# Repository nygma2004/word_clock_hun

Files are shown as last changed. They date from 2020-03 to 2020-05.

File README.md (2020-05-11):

# Word Clock Hungarian
This is my implementation of the Word Clock in Hungarian. Rest of the document is in Hungarian, English of this [document is here](README_EN.md).

## Változások
1.0
- Egyes mudulok külön header fájlokba lettek szétszedve

0.9
- Kód első verziója, az alap funckiók működnek
- Fényerő szabályzás még nem működik

## Főbb funkciók
- 10x10 mátrixban elhelyezett magyar szavakkal mutatja az aktuális időt 5 perces pontossággal
- Az egyes szavak színe a napszaknak megfelelően, nappal fehér, este kékes, naplementekor piros, napfelkeltekor narancssárgás és között 1 órát átmenet
- A pontos időt NTP szerverről szedi, kézi beállítás nincs
- Minden egész perckor rövid animálás van, amikor 8-10 véletlenszerű betű felvillan véletlenszerű színnel
- MQTT szerverre minden percben küld egy státus üzenetet: RSSI, uptime percben és a érzékelt fényerő
- MQTTn keresztül figyel egy sleep topic-ra, ahova ha 1-es érkezik akkor lekapcsolja a kijelzőt

A projekt teljes bemutatása ezen a videón megnézhető: 
https://youtu.be/ypevX-sNXiU

## Telepítés
- A kód Arudino IDE alatt kell elfordítani, ami ESP8266 alá be van konfigurálva
- Szükséges libraryk: PxMatrix LED MATRIX library by Dominic Buchstaller, Time by Michael Margolis (ezek megtalálhatók a Library Manager-ben), és persze az ESP alap libraryk, PubSubClient, stb.
### Projekt fájljai:
- WordClock_PxMatrix.ino: teljes programkód, ebben nem kell semmit módosítani ha ugyan ezt a kijelzőt használod és szintén magyar a kijelző
- settings.h: ebbe található a program beállításához szükséges össze paraméter
  - ANALOG_LOW: a legkisebb mért fény mennyiség (A0 analóg jel értéke)
  - BRIGHTNESS_LOW: a fenti érték esetén a kijező minimális fényereje
  - ANALOG_HIGH 120: a legnagyobb mért fény mennyiség (A0 analóg jel értéke)
  - BRIGHTNESS_HIGH: a fenti érték esetén a kijező maximális fényereje
  - ssid: wifi SSID
  - password: wifi jelszó
  - mqtt_server: MQTT szerver IPje, vagy maradjon üres ha nem kell
  - mqtt_user: MQTT usernév
  - mqtt_password: MQTT jelszó
  - clientID: MQTT klines ID
  - topicstatus: az MQTT topic amire az óra küldi percenként a státusz üzenetet
  - topicDebug: az MQTT topic amire a debug üzenetek mennek
  - topicSleep: az MQTT topic amire várja a sleep üzentetet
  - STATUS_UPDATE_INTERVAL: státusz MQTT üzenet gyakoriság másodpercben
  - ANIMATION_WORD_COUNT: minden percben a rövid animációban kigyújtütt betűk száma
  - ANIMATION_WORD_DELAY: az animációban az egyes betűk közötti késletetés miliszekundumban
- NTP.h fájl 63 sorától pár beállítás
  - GMTOffset: időzóna percben CET esetén ez 60
  - sm_latitude, sm_longtitude: földrajzi szélesség és hosszúság a napfelkelte, napnyugta számításhoz
- Arduino Board Configuration amit én használtam: LOLIN(WEMOS) D1 R2 mini, 4MB Flash size

## PCB
Minden részletesebb leírás nélkül egyelőre itt az általam használt PCB: https://www.pcbway.com/project/shareproject/PxMatrix_ESP8266_Driver.html
img könyvtárban van egy kép hogy néz ki. Ennek a leírása kicsit hosszú inkább mesélek róla a Youtube videóban.

## Hardver
- 32x32 pixeles, 192x192 mm P6 matrix kijelző: https://www.aliexpress.com/item/32658820147.html
- Wemos D1 mini klón: ebay, aliexpress, banggood, én már nem emlékszem az enyém honnan van
- 0.1 inch-es tűsor és csatlakozó 
- jumperek
- 0.2 inch-es csavaros 2 pólusú csatlakozó
- fotóellenállás

A PI és PO csatlakozóhoz nem vettem szabványos dugót és ajzatot, hanem sima egy soros tűsort és csatlakozót használtam, kéttőt egymás mellett és tökéletesen működik. Sőt a PO és a tápcsatlakozó olyan közel van egymáshoz hogy ott nem és férne el rendes ajzat. Viszont cserébe figyelni kell hogy dugja be az ember a dolgokat. Ahogy a képen is látszik a kijelzőn nyák lapján lévő nyilacskák balról jobbra mutassanak, és a PO csatlakozóba a szalagkábelt úgy kell bedugni hogy a csatlakozó oldalán a kiugrás a ESP felé legyen.

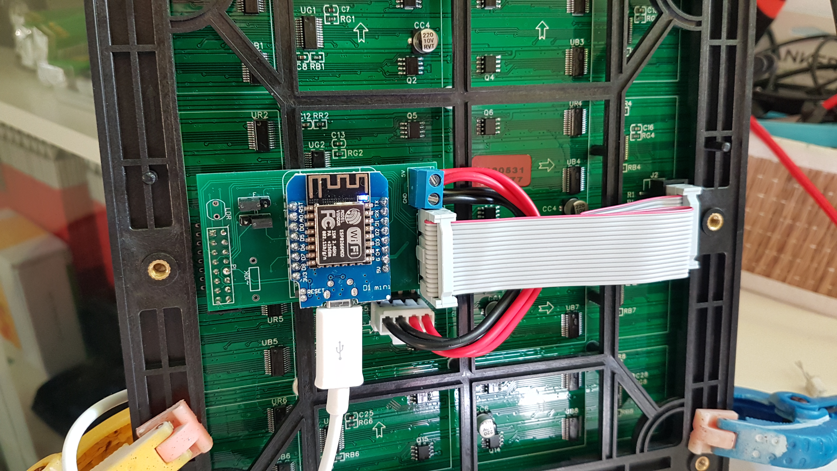
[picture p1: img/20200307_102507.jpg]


A nyákon a táp csatlakozó 5V és GND vezetéke össze van kötve a ESP 5V és GND lábával, így lehet a kijelzőt az ESPn keresztül microUSB csatlakozón keresztül hajtani, vagy más tápellátás esetén azt is a tápcsatlakozóra kötni és akkor azt ad áramot az ESPnek. Az én programom esetén ahol egyszerre sosem világít túl sok LED, USB tápról lehet a kijelzőt hajtani.
A P6-os matrix kijelző esetén a jumpereket a fenti képen látható módon kell elhelyezni.
Ez a Word Clock mivel egy időben az összes LEDnek csak viszonylag csak a kis része világít, átlagosan 250-300 mA-t fogyaszt. Így szerintem egy rendes 1A-es USB töltőről működtethető, nincs szükség külön 5V-os tápegységre.

## Fényerő szabályzás

A nyákon van hely egy fotoellenállás számára. Én itt nem vágtam le a fotoellenállás lábát, tettem rá zsugorcsövet és kihajlítottam hogy oldalt méreje a fényerőt. Ha jól emlékszem olyan LDR-t vettem ami 5K max megvilágítás mellett. Ehhez egy 5K-s ellenállást forrasztottam az ellenállás helyére (ahol a nyákon 10K felirat szerepel):

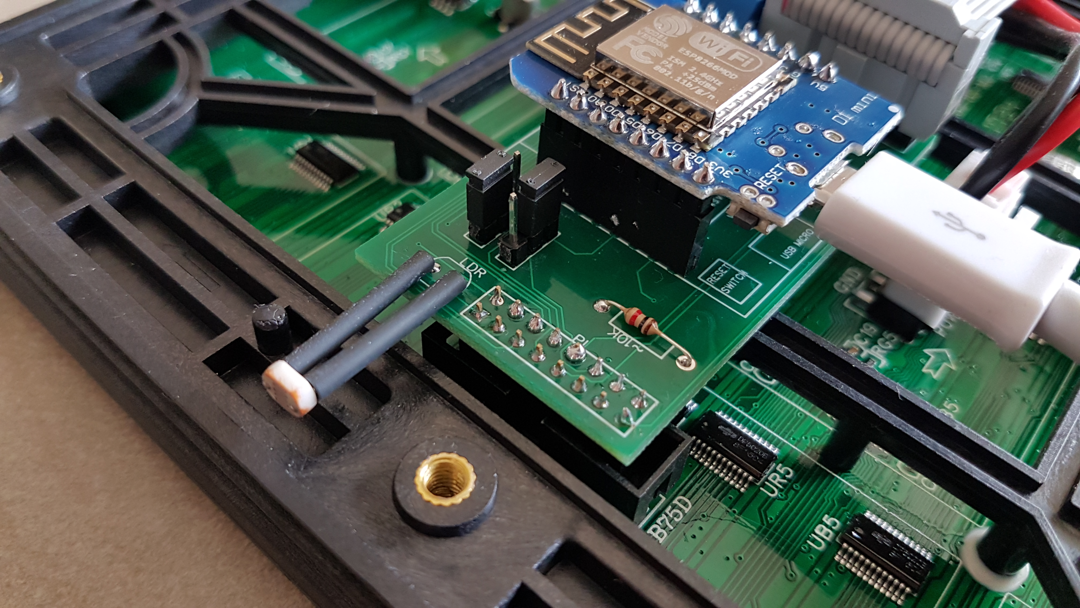
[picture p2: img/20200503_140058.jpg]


Így a max fényerő amit a ESP mér az olyan 400 körül van, de ahhoz hogy megállapítsam a háttérfényerősséget bőven elég. A beállításokban van 4 érték ami meghatározza hogy minimális analóg jel esetén mi legyen a kijelző fényereje és ugyan ez maximum esetén. Ezzel lehet játszani. Kettő között pedig arányosan alakul a fényerő mértéke.

## 3D nyomtatott alkatrészek és előlap
Az összes forrás és gcode fájl a 3D könyvtárban található. Teljes modell az alábbi részekből áll:
- 10x10 raster: ez a kijelzőt lefedő rács ami a 3x3 pixeles szavak megvilágító dobozokat előálltja
- 4 corners: ez jön a kijelző 4 sarkára. Ezt külön nyomtattam mert egyben nem fért volna bele a 3D nyomtató korlátaiba. Mind a 4 elem kicsit más, mindegyik a megfelelő sarokba kerüljön különben nem tökéletesen illeszkedik
- Lower corners: ez fogja meg a rácsot a másik oldalról, illetve eltartja a kijelzőt mondjuk a faltól hogy az elektronika elférjen
- Hanger support: egy kis kúp alakú elem amivel fel lehet akasztani egy szögre
- Cable holder: szintén egy kúpos elem amivel a kábelt lehet a falnál tartani, illetve hogy ne az USB csatlakozót húzza a kábel súlya

Itt látható az előlap a raszterrel és a 4 sarok elemmel amik pillanat ragasztóval vannak összeragasztva:
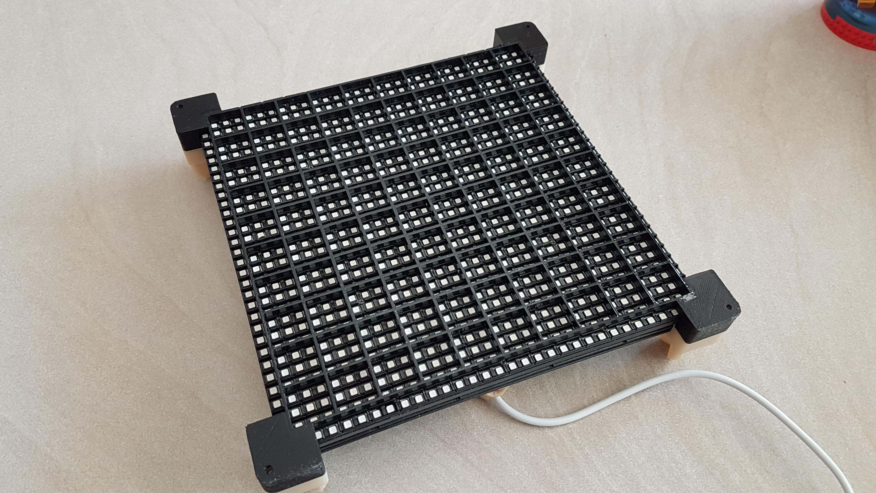
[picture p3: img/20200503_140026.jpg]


Kicsit közelebbről a sarok és hogyan illeszkedik a kijelző mélyedéseibe:
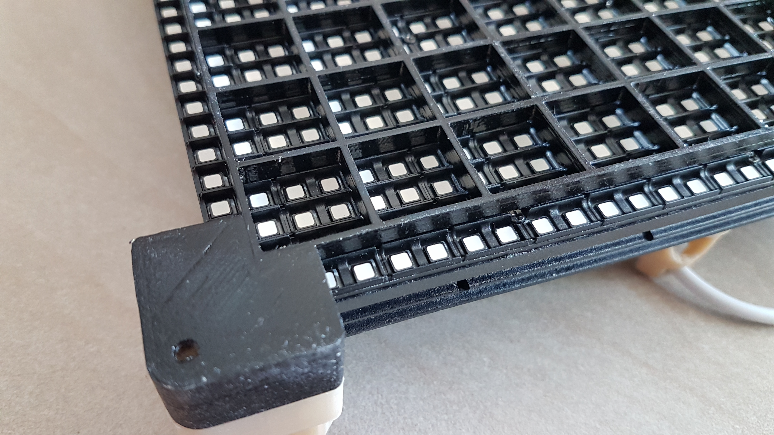
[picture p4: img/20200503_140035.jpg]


És a hátlap elemei:
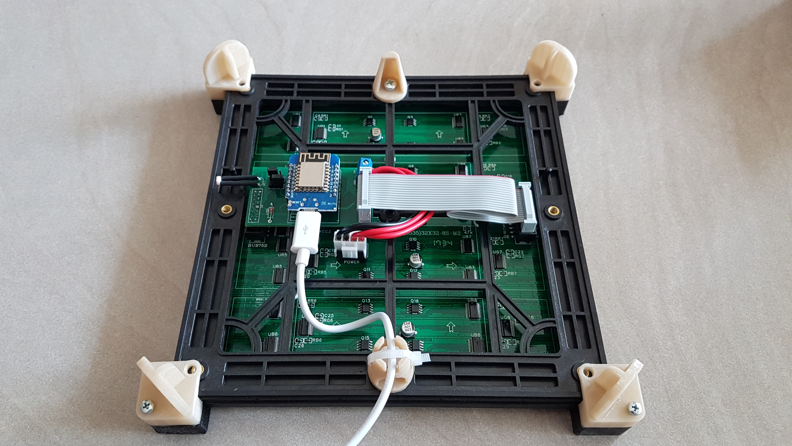
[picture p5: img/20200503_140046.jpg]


Az én órám esetén a számlap 1.5 mm vastag szénacél lemez, amiből a betűk lézervágással lettek kivágva. A lemezt 150-es csiszolópapírral kézzel csiszoltam és utána lakkal befújtam hogy ne rozsdásodjon. A lemez és a raszter háló közé pedig pausz papír került hogy ne látszanak a LED-ek. A design alkönyvtárban van egy dxf, dwg meg pdf terv is. Ezeket a fájlokat küldtem egy egy CNC cégnek és ez alapján vágták ki nekem az előlapot.

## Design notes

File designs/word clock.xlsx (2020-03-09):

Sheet: Sheet1
 |  | 0 | 1 | 2 | 3 | 4 | 5 | 6 | 7 | 8 | 9
0 |  | Ö | T | B | T | Í | Z | J | A | S | U
1 |  | P | E | R | C | C | E | L | E | W | O
2 |  | M | Ú | L | T | A | M | Ú | L | V | A
3 |  | H | Á | R | O | M | U | F | É | L | J
4 |  | N | E | G | Y | E | D | X | H | A | T
5 |  | N | É | G | Y | A | H | Á | R | O | M
6 |  | N | Y | O | L | C | Ö | T | H | É | T
7 |  | T | I | Z | E | N | E | G | Y | E | B
8 |  | T | I | Z | E | N | K | E | T | T | Ő
9 |  | K | I | L | E | N | C | Q | Ó | R | A
 | Calculator
 |  | 0 | 1 | 2 | 3 | 4 | 5 | 6 | 7 | 8 | 9
0 |  | Ö | T | B | T | Í | Z | J | A | S | U | 0x
1 |  | P | E | R | C | C | E | L | E | W | O | 1x
2 |  | M | Ú | L | T | A | M | Ú | L | V | A | 2x
3 |  | H | Á | R | O | M | U | F | É | L | J | 3x
4 |  | N | E | G | Y | E | D | X | H | A | T | 4x
5 |  | N | É | G | Y | A | H | Á | R | O | M | 5x
6 |  | N | Y | O | L | C | Ö | T | H | É | T | 6x
7 |  | T | I | Z | E | N | E | G | Y | E | B | 7x
8 |  | T | I | Z | E | N | K | E | T | T | Ő | 8x
9 |  | K | I | L | E | N | C | Q | Ó | R | A | 9x
 |  | 0 | 1 | 2 | 3 | 4 | 5 | 6 | 7 | 8 | 9

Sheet: Sheet2
3:00:00 | Ö | T | B | T | Í | Z | J | A | S | U | 0x
 | P | E | R | C | C | E | L | E | W | O | 1x
 | M | Ú | L | T | A | M | Ú | L | V | A | 2x
 | H | Á | R | O | M | U | F | É | L | J | 3x
 | N | E | G | Y | E | D | X | H | A | T | 4x
 | N | É | G | Y | A | H | Á | R | O | M | 5x
 | N | Y | O | L | C | Ö | T | H | É | T | 6x
 | T | I | Z | E | N | E | G | Y | E | B | 7x
 | T | I | Z | E | N | K | E | T | T | Ő | 8x
 | K | I | L | E | N | C | Q | Ó | R | A | 9x
 | 0 | 1 | 2 | 3 | 4 | 5 | 6 | 7 | 8 | 9
3:05:00 | Ö | T | B | T | Í | Z | J | A | S | U | 0x
 | P | E | R | C | C | E | L | E | W | O | 1x
 | M | Ú | L | T | A | M | Ú | L | V | A | 2x
 | H | Á | R | O | M | U | F | É | L | J | 3x
 | N | E | G | Y | E | D | X | H | A | T | 4x
 | N | É | G | Y | A | H | Á | R | O | M | 5x
 | N | Y | O | L | C | Ö | T | H | É | T | 6x
 | T | I | Z | E | N | E | G | Y | E | B | 7x
 | T | I | Z | E | N | K | E | T | T | Ő | 8x
 | K | I | L | E | N | C | Q | Ó | R | A | 9x
 | 0 | 1 | 2 | 3 | 4 | 5 | 6 | 7 | 8 | 9
3:10:00 | Ö | T | B | T | Í | Z | J | A | S | U | 0x
 | P | E | R | C | C | E | L | E | W | O | 1x
 | M | Ú | L | T | A | M | Ú | L | V | A | 2x
 | H | Á | R | O | M | U | F | É | L | J | 3x
 | N | E | G | Y | E | D | X | H | A | T | 4x
 | N | É | G | Y | A | H | Á | R | O | M | 5x
 | N | Y | O | L | C | Ö | T | H | É | T | 6x
 | T | I | Z | E | N | E | G | Y | E | B | 7x
 | T | I | Z | E | N | K | E | T | T | Ő | 8x
 | K | I | L | E | N | C | Q | Ó | R | A | 9x
 | 0 | 1 | 2 | 3 | 4 | 5 | 6 | 7 | 8 | 9
3:15:00 | Ö | T | B | T | Í | Z | J | A | S | U | 0x
 | P | E | R | C | C | E | L | E | W | O | 1x
 | M | Ú | L | T | A | M | Ú | L | V | A | 2x
 | H | Á | R | O | M | U | F | É | L | J | 3x
 | N | E | G | Y | E | D | X | H | A | T | 4x
 | N | É | G | Y | A | H | Á | R | O | M | 5x
 | N | Y | O | L | C | Ö | T | H | É | T | 6x
 | T | I | Z | E | N | E | G | Y | E | B | 7x
 | T | I | Z | E | N | K | E | T | T | Ő | 8x
 | K | I | L | E | N | C | Q | Ó | R | A | 9x
 | 0 | 1 | 2 | 3 | 4 | 5 | 6 | 7 | 8 | 9
3:20:00 | Ö | T | B | T | Í | Z | J | A | S | U | 0x
 | P | E | R | C | C | E | L | E | W | O | 1x
 | M | Ú | L | T | A | M | Ú | L | V | A | 2x
 | H | Á | R | O | M | U | F | É | L | J | 3x
 | N | E | G | Y | E | D | X | H | A | T | 4x
 | N | É | G | Y | A | H | Á | R | O | M | 5x
 | N | Y | O | L | C | Ö | T | H | É | T | 6x
 | T | I | Z | E | N | E | G | Y | E | B | 7x
 | T | I | Z | E | N | K | E | T | T | Ő | 8x
 | K | I | L | E | N | C | Q | Ó | R | A | 9x
 | 0 | 1 | 2 | 3 | 4 | 5 | 6 | 7 | 8 | 9
3:25:00 | Ö | T | B | T | Í | Z | J | A | S | U | 0x
 | P | E | R | C | C | E | L | E | W | O | 1x
 | M | Ú | L | T | A | M | Ú | L | V | A | 2x
 | H | Á | R | O | M | U | F | É | L | J | 3x
 | N | E | G | Y | E | D | X | H | A | T | 4x
 | N | É | G | Y | A | H | Á | R | O | M | 5x
 | N | Y | O | L | C | Ö | T | H | É | T | 6x
 | T | I | Z | E | N | E | G | Y | E | B | 7x
 | T | I | Z | E | N | K | E | T | T | Ő | 8x
 | K | I | L | E | N | C | Q | Ó | R | A | 9x
 | 0 | 1 | 2 | 3 | 4 | 5 | 6 | 7 | 8 | 9
3:30:00 | Ö | T | B | T | Í | Z | J | A | S | U | 0x
 | P | E | R | C | C | E | L | E | W | O | 1x
 | M | Ú | L | T | A | M | Ú | L | V | A | 2x
 | H | Á | R | O | M | U | F | É | L | J | 3x
 | N | E | G | Y | E | D | X | H | A | T | 4x
 | N | É | G | Y | A | H | Á | R | O | M | 5x
 | N | Y | O | L | C | Ö | T | H | É | T | 6x
 | T | I | Z | E | N | E | G | Y | E | B | 7x
 | T | I | Z | E | N | K | E | T | T | Ő | 8x
 | K | I | L | E | N | C | Q | Ó | R | A | 9x
 | 0 | 1 | 2 | 3 | 4 | 5 | 6 | 7 | 8 | 9
3:35:00 | Ö | T | B | T | Í | Z | J | A | S | U | 0x
 | P | E | R | C | C | E | L | E | W | O | 1x
 | M | Ú | L | T | A | M | Ú | L | V | A | 2x
 | H | Á | R | O | M | U | F | É | L | J | 3x
 | N | E | G | Y | E | D | X | H | A | T | 4x
 | N | É | G | Y | A | H | Á | R | O | M | 5x
 | N | Y | O | L | C | Ö | T | H | É | T | 6x
 | T | I | Z | E | N | E | G | Y | E | B | 7x
 | T | I | Z | E | N | K | E | T | T | Ő | 8x
 | K | I | L | E | N | C | Q | Ó | R | A | 9x
 | 0 | 1 | 2 | 3 | 4 | 5 | 6 | 7 | 8 | 9
3:40:00 | Ö | T | B | T | Í | Z | J | A | S | U | 0x
 | P | E | R | C | C | E | L | E | W | O | 1x
 | M | Ú | L | T | A | M | Ú | L | V | A | 2x
 | H | Á | R | O | M | U | F | É | L | J | 3x
 | N | E | G | Y | E | D | X | H | A | T | 4x
 | N | É | G | Y | A | H | Á | R | O | M | 5x
 | N | Y | O | L | C | Ö | T | H | É | T | 6x
 | T | I | Z | E | N | E | G | Y | E | B | 7x
 | T | I | Z | E | N | K | E | T | T | Ő | 8x
 | K | I | L | E | N | C | Q | Ó | R | A | 9x
 | 0 | 1 | 2 | 3 | 4 | 5 | 6 | 7 | 8 | 9
3:45:00 | Ö | T | B | T | Í | Z | J | A | S | U | 0x
 | P | E | R | C | C | E | L | E | W | O | 1x
 | M | Ú | L | T | A | M | Ú | L | V | A | 2x
 | H | Á | R | O | M | U | F | É | L | J | 3x
 | N | E | G | Y | E | D | X | H | A | T | 4x
 | N | É | G | Y | A | H | Á | R | O | M | 5x
 | N | Y | O | L | C | Ö | T | H | É | T | 6x
 | T | I | Z | E | N | E | G | Y | E | B | 7x
 | T | I | Z | E | N | K | E | T | T | Ő | 8x
 | K | I | L | E | N | C | Q | Ó | R | A | 9x
 | 0 | 1 | 2 | 3 | 4 | 5 | 6 | 7 | 8 | 9
3:50:00 | Ö | T | B | T | Í | Z | J | A | S | U | 0x
 | P | E | R | C | C | E | L | E | W | O | 1x
 | M | Ú | L | T | A | M | Ú | L | V | A | 2x
 | H | Á | R | O | M | U | F | É | L | J | 3x
 | N | E | G | Y | E | D | X | H | A | T | 4x
 | N | É | G | Y | A | H | Á | R | O | M | 5x
 | N | Y | O | L | C | Ö | T | H | É | T | 6x
 | T | I | Z | E | N | E | G | Y | E | B | 7x
 | T | I | Z | E | N | K | E | T | T | Ő | 8x
 | K | I | L | E | N | C | Q | Ó | R | A | 9x
 | 0 | 1 | 2 | 3 | 4 | 5 | 6 | 7 | 8 | 9
3:55:00 | Ö | T | B | T | Í | Z | J | A | S | U | 0x
 | P | E | R | C | C | E | L | E | W | O | 1x
 | M | Ú | L | T | A | M | Ú | L | V | A | 2x
 | H | Á | R | O | M | U | F | É | L | J | 3x
 | N | E | G | Y | E | D | X | H | A | T | 4x
 | N | É | G | Y | A | H | Á | R | O | M | 5x
 | N | Y | O | L | C | Ö | T | H | É | T | 6x
 | T | I | Z | E | N | E | G | Y | E | B | 7x
 | T | I | Z | E | N | K | E | T | T | Ő | 8x
 | K | I | L | E | N | C | Q | Ó | R | A | 9x
 | 0 | 1 | 2 | 3 | 4 | 5 | 6 | 7 | 8 | 9

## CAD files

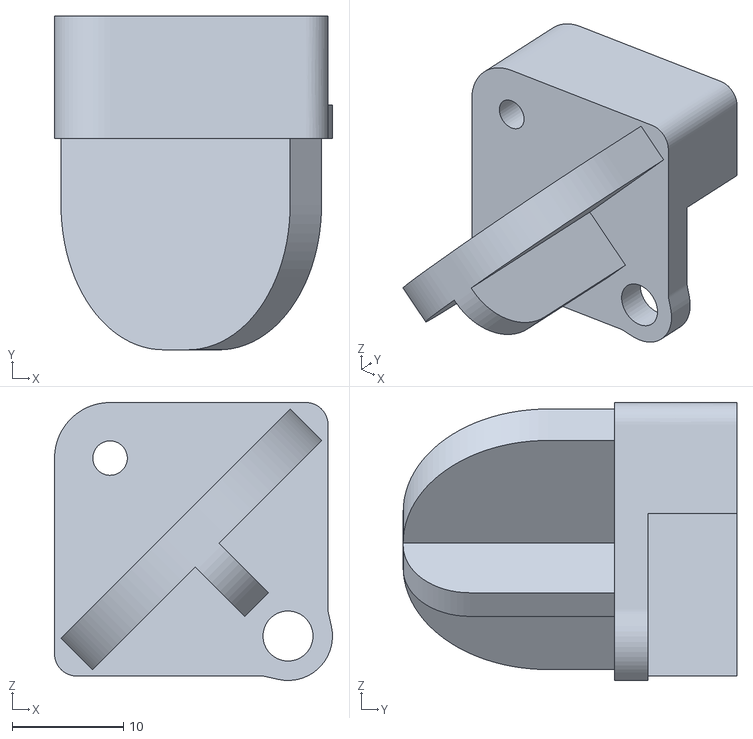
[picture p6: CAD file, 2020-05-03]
3D/Lower Corner.stl
25.0 x 30.0 x 25.0

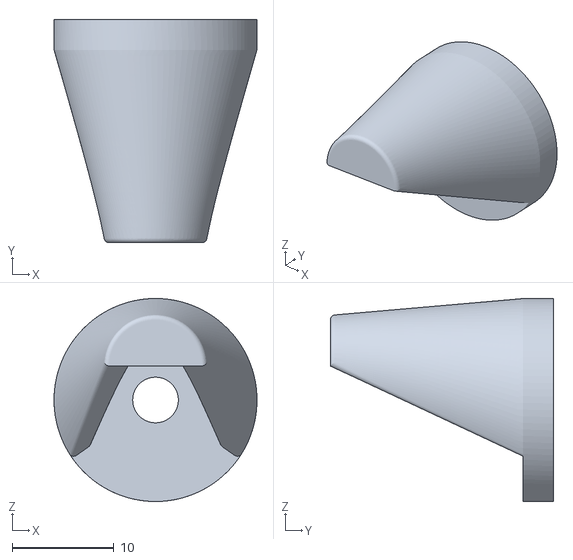
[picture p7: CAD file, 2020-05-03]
3D/Hanger support.stl
20.0 x 22.0 x 20.0

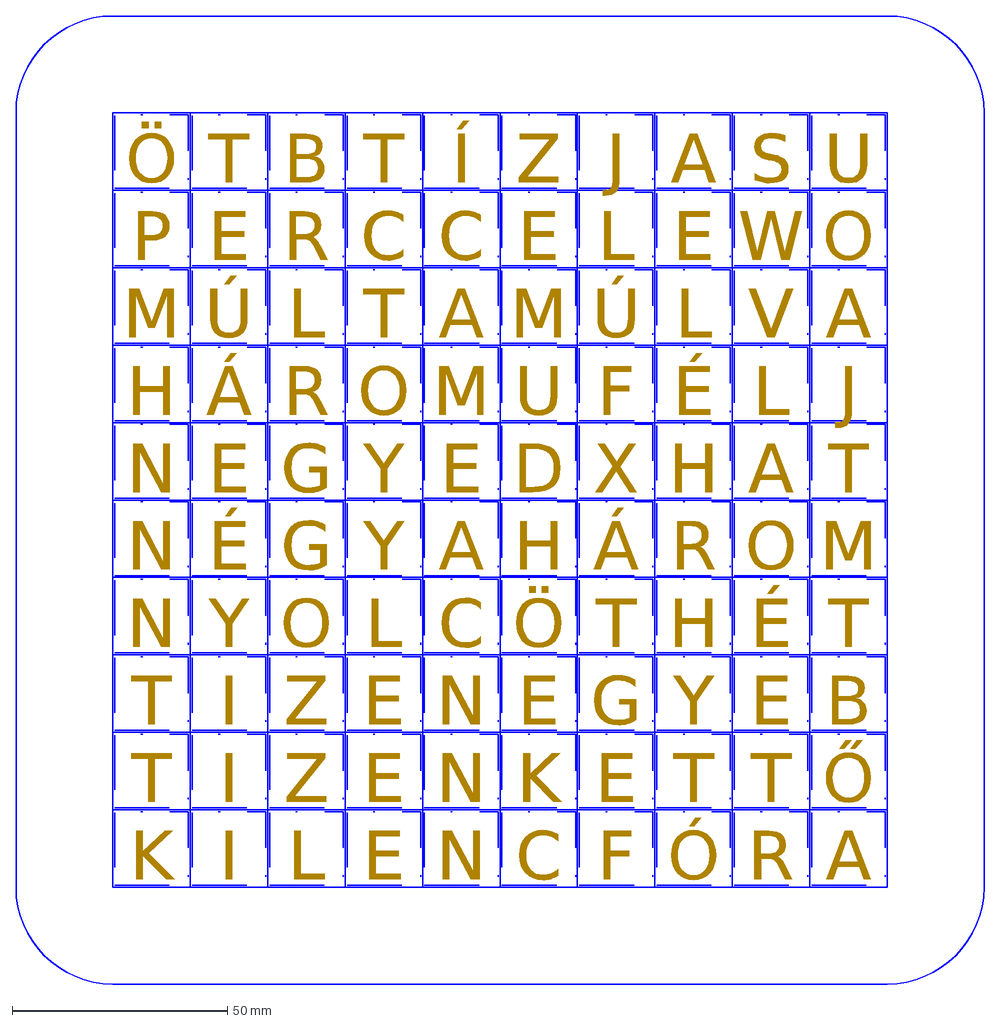
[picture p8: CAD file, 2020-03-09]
designs/word_clock_P6matrix.dxf
Ö
T
B
Í
Z
J
A
S
U
P
E
R
C
L
W
O
M
Ú
V
H
Á
F
É
N
G
Y
D
X
I
K
Ő
Ó

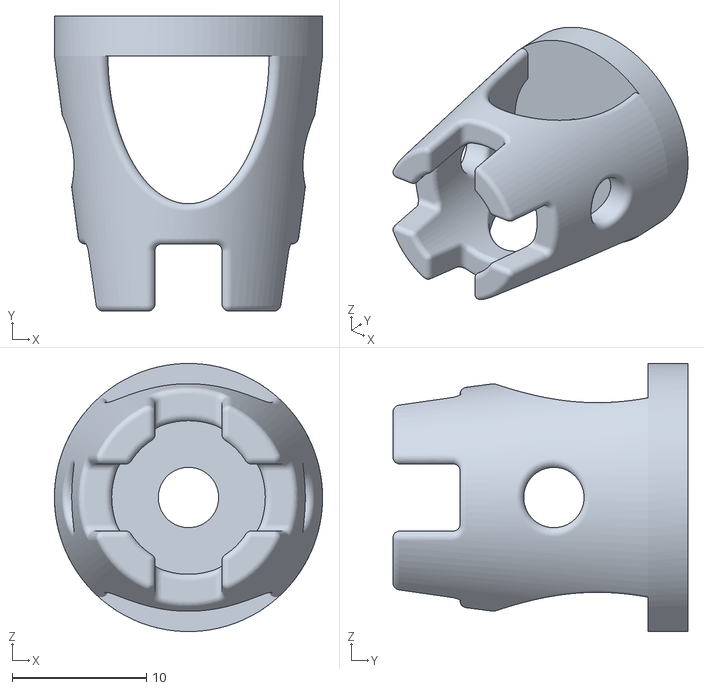
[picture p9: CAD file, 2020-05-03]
3D/Cable holder.stl
20.0 x 22.0 x 20.0

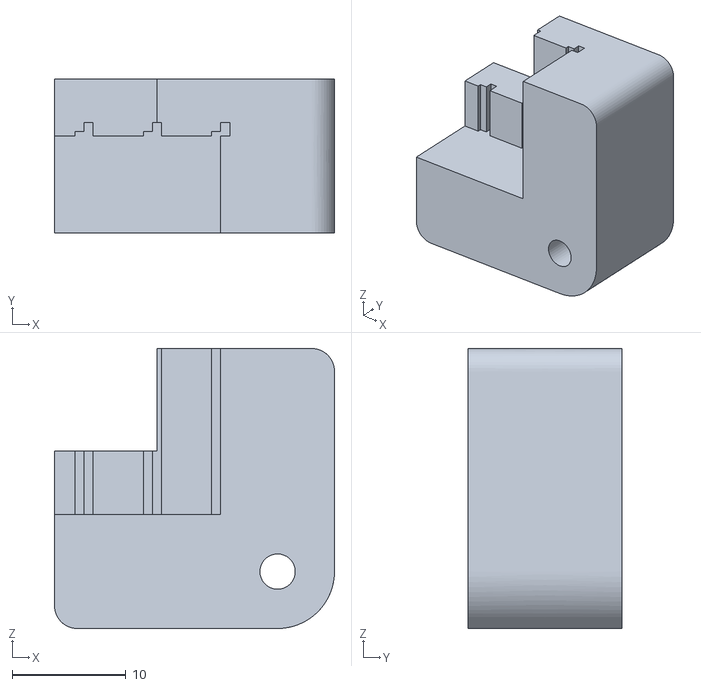
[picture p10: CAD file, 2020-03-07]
3D/Corner 3.stl
24.6 x 13.5 x 24.6

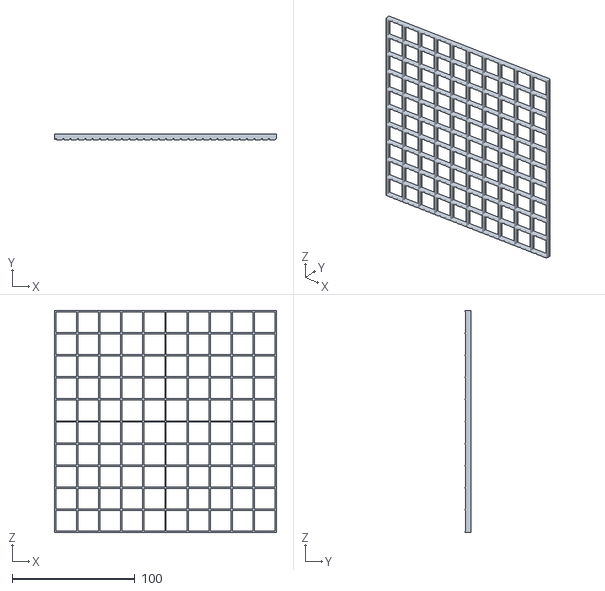
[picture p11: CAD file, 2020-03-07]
3D/10x10 raster.stl
181.2 x 5.00 x 181.2

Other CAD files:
designs/Word_clock_P6_2000.dwg
3D/Corner 1.stl
3D/Corner 2.stl
3D/Corner 4.stl

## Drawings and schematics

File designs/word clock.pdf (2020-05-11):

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

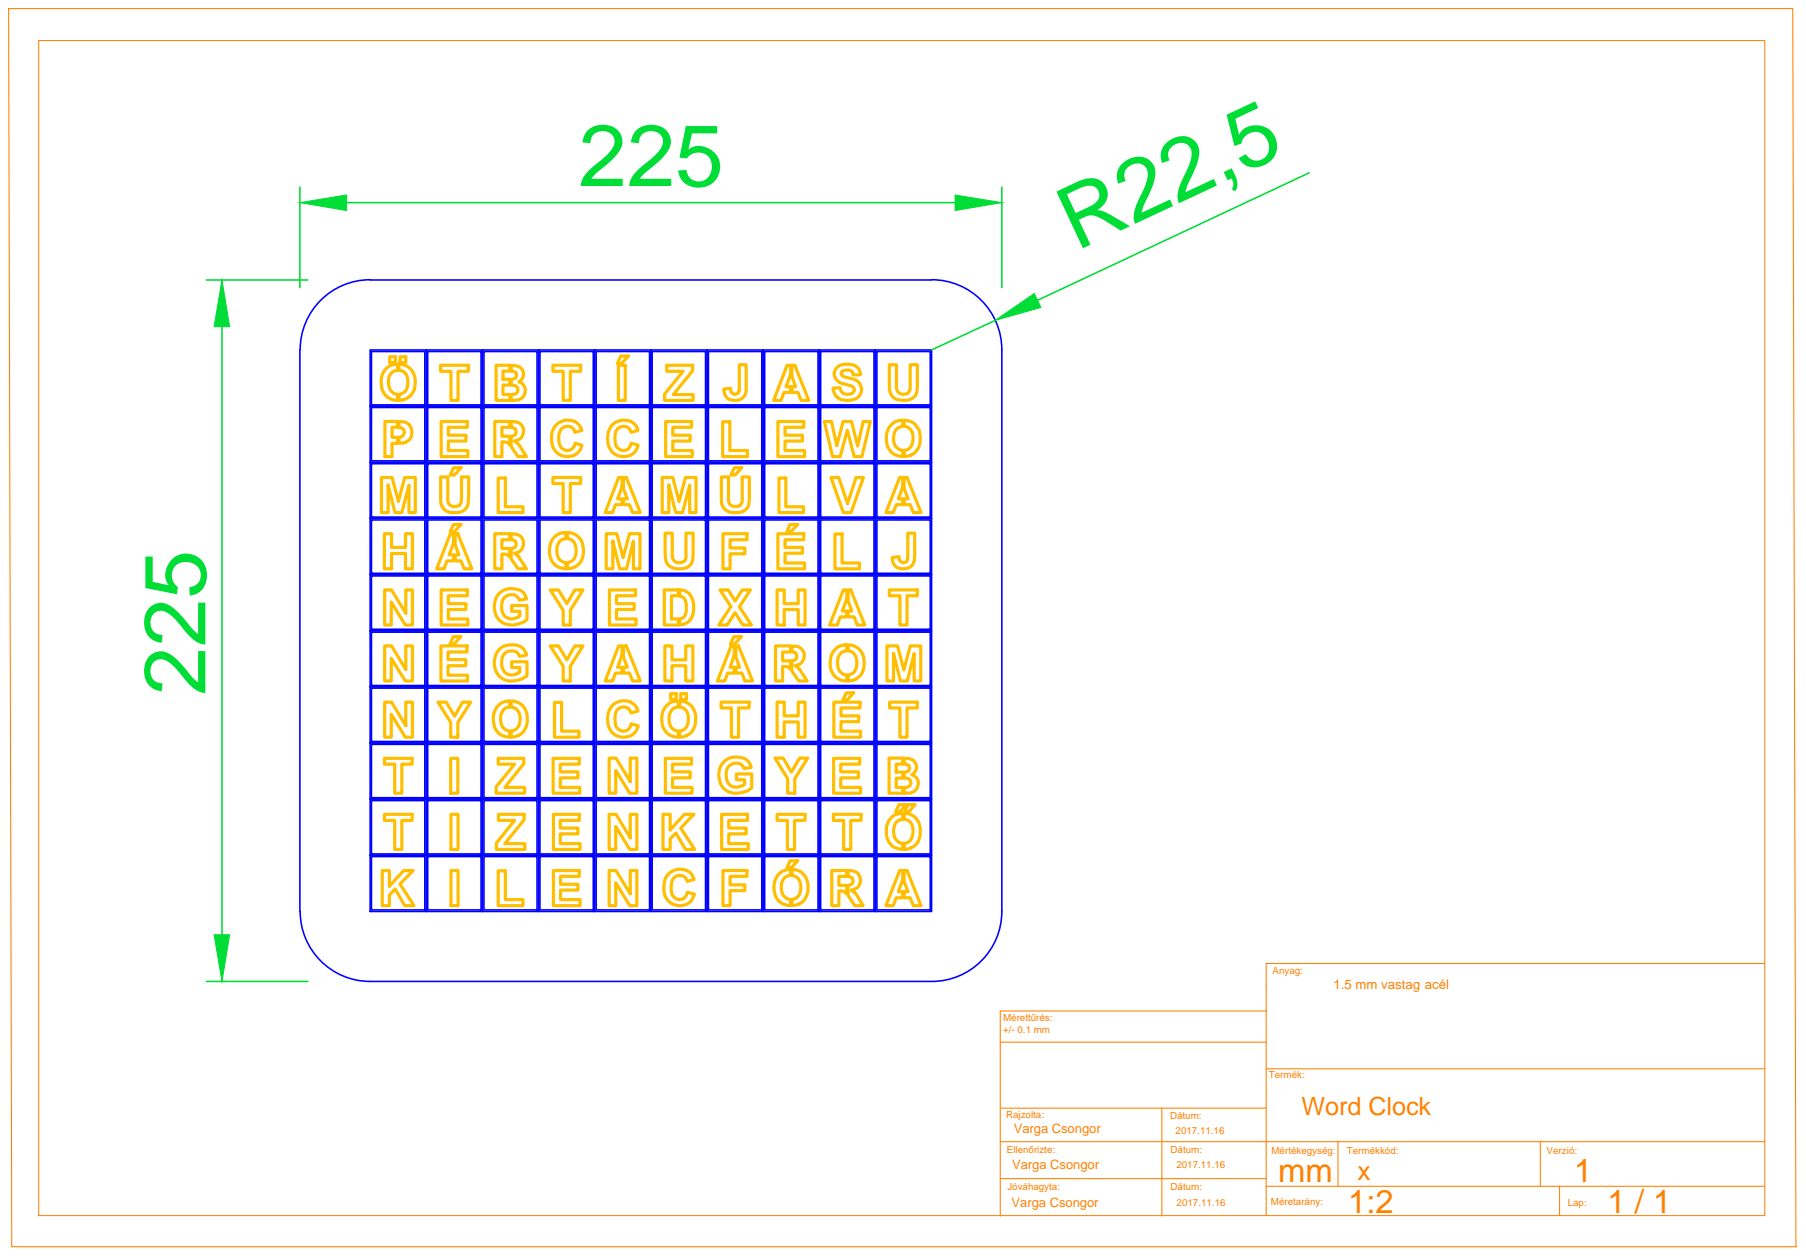
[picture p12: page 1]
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

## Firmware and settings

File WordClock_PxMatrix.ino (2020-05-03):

// Word Clock Hungarian
// Repo: https://github.com/nygma2004/word_clock_hun
// author: Csongor Varga, csongor.varga@gmail.com

#include <ESP8266WiFi.h>
#include <ESP8266WebServer.h>
#include <ESP8266mDNS.h>
#include <PubSubClient.h>           // MQTT support
#include <WiFiUdp.h>                // Added for NTP functionality
#include "NTP.h"
#include "settings.h"
#include "Words_HUN.h"

#include <PxMatrix.h>
#include <Time.h>
#include <TimeLib.h>
#include <sunMoon.h>                // Sunrise, sunset calculation
extern "C" {
#include "user_interface.h"
}

#define PxMATRIX_COLOR_DEPTH 8
#define PxMATRIX_MAX_HEIGHT 32
#define PxMATRIX_MAX_WIDTH 32

#ifdef ESP32

#define P_LAT 22
#define P_A 19
#define P_B 23
#define P_C 18
#define P_D 5
#define P_E 15
#define P_OE 2
hw_timer_t * timer = NULL;
portMUX_TYPE timerMux = portMUX_INITIALIZER_UNLOCKED;

#endif

#ifdef ESP8266

#include <Ticker.h>
Ticker display_ticker;
#define P_LAT 16
#define P_A 5
#define P_B 4
#define P_C 15
#define P_D 12
#define P_E 0
#define P_OE 2
#define DEBUG 1

#endif

// PxMatrix definition
//PxMATRIX display(32,16,P_LAT, P_OE,P_A,P_B,P_C);
PxMATRIX display(32,32,P_LAT, P_OE,P_A,P_B,P_C,P_D);   // This is the correct setting for a P6 32x32 1/8 scan matrix
//PxMATRIX display(64,64,P_LAT, P_OE,P_A,P_B,P_C,P_D,P_E);

String NTPtime = "--:--";
unsigned long lastTick, uptime, lastNTP, seconds, epoch2, sec, lastANI;
byte LEDR, LEDG, LEDB;
byte updateScreen, aniSequence; 
int clockhour, clockfivemin;
time_t sRise;
time_t sSet;
String mqttStat = "";
String message;
int brightnessAnalog = 0;
os_timer_t myTimer;

MDNSResponder mdns;
ESP8266WebServer server(80);
WiFiClient espClient;
PubSubClient mqtt(mqtt_server, 1883, 0, espClient);

#ifdef ESP8266
// ISR for display refresh
void display_updater()
{
  display.display();
}
#endif

#ifdef ESP32
void IRAM_ATTR display_updater(){
  // Increment the counter and set the time of ISR
  portENTER_CRITICAL_ISR(&timerMux);
  display.displayTestPattern(70);
  portEXIT_CRITICAL_ISR(&timerMux);
}
#endif


// Some standard colors used for the animation each minute
uint16_t myRED = display.color565(255, 0, 0);
uint16_t myGREEN = display.color565(0, 255, 0);
uint16_t myBLUE = display.color565(0, 0, 255);
uint16_t myWHITE = display.color565(255, 255, 255);
uint16_t myYELLOW = display.color565(255, 255, 0);
uint16_t myCYAN = display.color565(0, 255, 255);
uint16_t myMAGENTA = display.color565(255, 0, 255);
uint16_t myBLACK = display.color565(128, 128, 128);

uint16_t myCOLORS[8]={myRED,myGREEN,myBLUE,myYELLOW,myCYAN,myMAGENTA,myBLACK,myWHITE};
int i =0;

void setup() {
    // Serial setup for debug messages
    Serial.begin(9600);
    Serial.println();
    Serial.println("Word Clock - Hungarian");
  
    // Px Matrix display setup
    display.begin(8);                      // 1/8 scan display
    display.setFastUpdate(true); 
    display.setScanPattern(WZAGZIG);
    display.setColorOrder(BBGGRR);         // My matrix uses BBGGRR color order instead of RRGGBB
    display.setBrightness(70);
    display.flushDisplay();
  
    uptime = 0;
    sec = 0;
    seconds = -1;
    updateScreen = 0;
    aniSequence = 0;
  
  
    // interrupt setup for the display
    #ifdef ESP8266
      display_ticker.attach(0.002, display_updater);
    #endif
  
    #ifdef ESP32
      timer = timerBegin(0, 80, true);
      timerAttachInterrupt(timer, &display_updater, true);
      timerAlarmWrite(timer, 2000, true);
      timerAlarmEnable(timer);
    #endif

    Serial.print(F("Connecting to Wifi"));
    WiFi.mode(WIFI_STA);
    WiFi.begin(ssid, password);
  
    while (WiFi.status() != WL_CONNECTED) {
      delay(500);
      Serial.print(F("."));
      seconds++;
      drawWordPixel(seconds%10,seconds/10,myRED);
      if (seconds>180) {
        // reboot the ESP if cannot connect to wifi
        ESP.restart();
      }
    }

    Serial.println("");
    Serial.print(F("Connected to "));
    Serial.println(ssid);
    Serial.print(F("IP address: "));
    Serial.println(WiFi.localIP());
    Serial.print(F("Signal [RSSI]: "));
    Serial.println(WiFi.RSSI());

    // Set up the MDNS and the HTTP server
    if (mdns.begin("Word Clock", WiFi.localIP())) {
      Serial.println(F("MDNS responder started"));
      seconds++;
      drawWordPixel(seconds%10,seconds/10,myYELLOW);
    }  
    server.on("/", [](){                        // Dummy page
      server.send(200, "text/plain", "Word Clock");
    });
    server.begin();
    Serial.println(F("HTTP server started"));
    seconds++;
    drawWordPixel(seconds%10,seconds/10,myYELLOW);

    // Start UDP for NTP function
    Serial.println(F("Starting UDP"));
    udp.begin(localPort);
    Serial.print(F("Local port: "));
    Serial.println(udp.localPort());
    seconds++;
    drawWordPixel(seconds%10,seconds/10,myGREEN);
    requestNTPUpdate();
    // Initialize sunrise and sunset calculator
    sm.init(GMTOffset, sm_latitude, sm_longtitude);  
    seconds++;
    drawWordPixel(seconds%10,seconds/10,myGREEN);
  
    // Update the screen brightness
    BrightnessCheck(); 

    // Timer interrupt for the clock functions
    os_timer_setfn(&myTimer, timerCallback, NULL);
    os_timer_arm(&myTimer, 1000, true);

    // Set up the MQTT server connection
    if (mqtt_server!="") {
      mqtt.setServer(mqtt_server, 1883);
      mqtt.setCallback(MQTTcallback);
      reconnect();
    }
    seconds++;
    drawWordPixel(seconds%10,seconds/10,myYELLOW);
    randomSeed(millis());
    seconds = 0;



}

// MQTT reconnect logic
void reconnect() {
  // Loop until we're reconnected
  while (!mqtt.connected()) {
    Serial.print("Attempting MQTT connection...");
    // Attempt to connect
    if (mqtt.connect(clientID, mqtt_user, mqtt_password)) {
      Serial.println(F("connected"));
      // ... and resubscribe
      mqtt.subscribe(topicSleep);
      Serial.print(F("Subscribed to "));
      Serial.println(topicSleep);
    } else {
      Serial.print(F("failed, rc="));
      Serial.print(mqtt.state());
      Serial.println(F(" try again in 5 seconds"));
      // Wait 5 seconds before retrying
      delay(5000);
    }
  }
}

// This routing just puts the status string together which will be sent over MQTT
void refreshStats() {
  // Initialize the strings for MQTT 
  mqttStat = "{\"rssi\":";
  mqttStat += WiFi.RSSI();
  mqttStat += ",\"uptime\":";
  mqttStat += uptime;
  mqttStat += ",\"brightness\":";
  mqttStat += brightnessAnalog;
  mqttStat += "}";
}

// Set the screen brightness based on the light sensor analog input
void BrightnessCheck() {
  // Check for the photoresistor and set the brightness level
  brightnessAnalog = analogRead(0);
  if (brightnessAnalog<=ANALOG_LOW) {
    display.setBrightness(BRIGHTNESS_LOW);
    return;
  }
  if (brightnessAnalog>=ANALOG_HIGH) {
    display.setBrightness(BRIGHTNESS_HIGH);
    return;
  }
  display.setBrightness(BRIGHTNESS_LOW+(BRIGHTNESS_HIGH-BRIGHTNESS_LOW)*(brightnessAnalog-ANALOG_LOW)/(ANALOG_HIGH-ANALOG_LOW));
}

// Process the data returned by the NTP server
void handleNTPResponse() {
  // Check for NTP response
  int cb = udp.parsePacket();
  if (cb!=0) {
    if (NTPUpdateMillis == 0) {
      // This is only true after boot
      //currentPage = 0xff; // set the clock page
      //pageChange = true; // transition in the clock page
    }
    NTPUpdateMillis = millis();
    NTPRequested = false;
    udp.read(packetBuffer, NTP_PACKET_SIZE); // read the packet into the buffer
    unsigned long highWord = word(packetBuffer[40], packetBuffer[41]);
    unsigned long lowWord = word(packetBuffer[42], packetBuffer[43]);
    unsigned long secsSince1900 = highWord << 16 | lowWord;
    const unsigned long seventyYears = 2208988800UL;
    epoch = secsSince1900 - seventyYears;
    if (summerTime(epoch)) {
      epoch += 3600; // add 1 hour DST
    }
    epoch += GMTOffset * 60;
    // TEST DATA
    //epoch = 1548396000;
    Serial.print(F("NTP Update (epoch): "));
    Serial.println(epoch);
    Serial.print(F("NTP Update (time): "));
    printDate(epoch);  Serial.println("");

    // Sunrise and Sunset calculations
    sRise = sm.sunRise(epoch);
    sSet  = sm.sunSet(epoch);
    if (summerTime(epoch)) {
      sRise += 3600; // add 1 hour DST
      sSet += 3600; // add 1 hour DST
    }
    renderTime();
    Serial.print(F("Today sunrise and sunset: "));
    Serial.print(sRise); Serial.print(F("; "));
    Serial.print(sSet);  Serial.println("");
    //printDate(sRise); Serial.print(F("; "));
    //printDate(sSet);  Serial.println("");
    if (updateScreen==0) {
      // go to the time screen since now we have the correct time - only in the beginning
      updateScreen = 1;
    }
  }  
}


// HTTP request handle for the page update
void handleUpdateCommand() { 
  message = "Word Clock";
  server.send(200, "text/plain", message);          //Returns the HTTP response
}

// MQTT callback function
void MQTTcallback(char* topic, byte* payload, unsigned int length) {
  // Convert the incoming byte array to a string
  String strTopic = String((char*)topic);
  payload[length] = '\0'; // Null terminator used to terminate the char array
  String message = (char*)payload;

  Serial.print(F("Message arrived on topic: ["));
  Serial.print(strTopic);
  Serial.print(F("], "));
  Serial.println(message);

  if (strTopic==(String)topicSleep) {
    Serial.print(F("Sleep: "));
    if (atoi((char *)payload)==1) {
      // Sleep mode starts
      updateScreen = 200;
      display.clearDisplay();
      Serial.print(F("start"));
    } else {
      updateScreen = 1;
      Serial.print(F("end"));
    }
    Serial.println();
  }
}

// Calculate the color of the words. There are different color for daytime (white) , nighttime (blue)
// sunrise (orange) and sunset (red). This function also calculates transition for each of these phases
void calculateColors() {
int trans = 3600; // transition period in and out of sunrise and sunset (1 hour)
  // the current NTP corrected time is stored in epoch2. It is assumed that it is updated by the flow
String state = "";
String msg = "";
  if((epoch2>=sRise+trans)&&(epoch2<=sSet-trans)) {
    // it is day time now (1 hour after sunrise and 1 hour before sunset
    state = "daytime";
    LEDR = 255;
    LEDG = 255;
    LEDB = 255;
  } else {
    if((epoch2<=sRise-trans)||(epoch2>=sSet+trans)) {
      // it is night time now  (1 hour after sunset 1 hour hour before sunset
      state = "nighttime";
      LEDR = 76;
      LEDG = 103;
      LEDB = 255;      
    } else {
      if((epoch2>sRise-trans)&&(epoch2<=sRise)) {
        // transitioning from night to sunrise. Sunrise: 255,193,94
        state = "night to sunrise";
        float phase = ((float)sRise - (float)epoch2 ) / 3600; // 1 in the beginning and reduces to 0
        LEDR = 255-(int) ((255-76)*phase);
        LEDG = 193-(int) ((193-103)*phase);
        LEDB =94+(int) ((255-94)*phase);
      }
      if((epoch2>sRise)&&(epoch2<sRise+trans)) {
        // transitioning from sunrise to daytime
        float phase = ((float)epoch2 - (float)sRise) / 3600; // 0 in the beginning and increases to 1
        state = "sunrise to daytime";
        LEDR = 255;
        LEDG = 193+(int) ((255-193)*phase);
        LEDB = 94+(int) ((255-94)*phase);
      }
      if((epoch2>sSet-trans)&&(epoch2<=sSet)) {
        // transitioning from daytime to sunset. Sunset: 255,90,68
        float phase = ((float)sSet - (float)epoch2) / 3600; // 1 in the beginning and decreases to 0
        state = "daytime to sunset";
        LEDR = 255;
        LEDG = 90+(int) ((255-90)*phase);
        LEDB = 68+(int) ((255-68)*phase);
      }
      if((epoch2>sSet)&&(epoch2<sSet+trans)) {
        // transitioning from sunset to nighttime
        float phase = ((float)epoch2 - (float)sSet) / 3600; // 0 in the beginning and increases to 1
        state = "sunset to nighttime";
        LEDR = 255-(int) ((255-76)*phase);
        LEDG = 90+(int) ((103-90)*phase);
        LEDB = 68+(int) ((255-68)*phase);
      }
    }
  }
  msg = NTPtime + String(" | ") + state + String(" | ") + LEDR + String(",") + LEDG + String(",") + LEDB;
  Serial.println(msg);
  #ifdef DEBUG
    if (mqtt_server!="") {
      mqtt.publish(topicDebug, msg.c_str());
    }
  #endif
}

// Calculate the current time using the millis passed since the last NTP update
void renderTime() {
  // Construct the current time string
  if (NTPUpdateMillis>0) {
    NTPtime  = "";
    // TEST
    //epoch2 = epoch;
    epoch2 = epoch+((millis()-NTPUpdateMillis) / 1000);
    if (((epoch2 % 86400L) / 3600)<10) {
      // add leading zero if hour is less than 10
      NTPtime  += "0";
    }
    NTPtime  += (epoch2 % 86400L) / 3600; // print the hour (86400 equals secs per day)
    NTPtime  += ":";
    if ( ((epoch2 % 3600) / 60) < 10 ) {
      // In the first 10 minutes of each hour, we'll want a leading '0'
      NTPtime  += "0";
    }
    NTPtime  += (epoch2  % 3600) / 60; // print the minute (3600 equals secs per minute)
  } else {
    NTPtime = "--:--";
  }  
}

// This is the 1 second timer callback function for the general housekeeping activities
// change the screen (animation every minute) and status update
void timerCallback(void *pArg) {
  sec++;
  seconds++;
  if ((sec % 60==0)&&(updateScreen!=2)&&(updateScreen!=200)) {
    updateScreen = 2;
    aniSequence = 0;
  }
  if (seconds==STATUS_UPDATE_INTERVAL) {
    // Send MQTT update
    BrightnessCheck(); 
    refreshStats();
    if (mqtt_server!="") {
      mqtt.publish(topicStatus, mqttStat.c_str());
      Serial.print(F("Status: "));
      Serial.println(mqttStat);
    }
    seconds = 0;
  }
}

//Bubble sort of an array
void isort(byte *a, int n)
{
 for (int i = 1; i < n; ++i)
 {
   int j = a[i];
   int k;
   for (k = i - 1; (k >= 0) && (j < a[k]); k--)
   {
     a[k + 1] = a[k];
   }
   a[k + 1] = j;
 }
}

// This method is responsible for updating the words on the clockface. It also does the transitioning in of the words
// this should only be called when the clockface needs to change (every 5 minutes)
void updateWords() {
  unsigned long temp;
  String msg = "";
  temp = epoch2; // current time in seconds calculated from the NTP time
  temp = epoch2 / 60; // convert to minutes
  clockfivemin = temp % 60 / 5; // convert to 5 minute time
  clockhour = temp / 60 % 24; // convert to hour of the day
  msg = String("hour=") + clockhour + String(", 5min=") + clockfivemin;
  // convert 24h hours to 12h hours
  if (clockhour > 12) {
    clockhour = clockhour - 12; 
  }
  // the below statement is required as from quarter past you say the next hour (in Hungarian)
  if (clockfivemin>2) {
    clockhour++;
    if (clockhour == 13) clockhour = 1;  // handle roll over beyond 12 o'clock
  }
  if (clockhour == 0) {
    clockhour = 12; // zero hour is called 12 o'clock
  }
  msg += String(" -> hour=") + clockhour + String(", 5min=") + clockfivemin;
  
  byte pixels[50]; // this will be my temporary array to hold all the pixels for the clockface
  int pixelCount = 0;
  // copy all pixels from the hour array to the pixels array
  msg += String(" | H=");
  for(int i=0;i<HOURSIZE;i++) {
    if (hours[clockhour][i]==255) break;
    pixels[pixelCount] = hours[clockhour][i];
    msg += pixels[pixelCount] + String(",");
    pixelCount++;
  }
  // copy all pixels from the minute array to the pixels array
  msg += String(" | M=");
  for(int i=0;i<MINSIZE;i++) {
    if (minutes[clockfivemin][i]==255) break;
    pixels[pixelCount] = minutes[clockfivemin][i];
    msg += pixels[pixelCount] + String(",");
    pixelCount++;
  }

  // sort the array
  isort(pixels,pixelCount);

  Serial.println(msg);
  #ifdef DEBUG
    if (mqtt_server!="") {
      mqtt.publish(topicDebug, msg.c_str());
    }
  #endif
    
  uint16_t currentColor = display.color565(LEDR, LEDG, LEDB);
  // display all pixels one by one
  display.clearDisplay();
  for(int i=0;i<pixelCount;i++) {
    drawWordPixel(pixels[i]%10,pixels[i]/10,currentColor);
    
    yield();
    delay(40);
  }
}

// Small animation every minute. Randomly light up 10 words. This gets called 10 times in the main loop 
// not to lock the main execution
void updateAnimation() {
  //Serial.println("Animation starts...");
    int randNumber = random(100);
    drawWordPixel(randNumber%ANIMATION_WORD_COUNT,randNumber/ANIMATION_WORD_COUNT,myCOLORS[clockfivemin % 6]);
    aniSequence++;
}

// Letters are stored as numbers 0-100, first line 0-9, second line 10-19 and so on
// this method converts this to pixels on the display, in my case I am using a 32x32 matrix
// outer row and columns not used, remaining 30x30 grid is broken up to 3x3 groups for each letter
void drawWordPixel(int16_t x, int16_t y, uint16_t color) {
    // update 3x3 pixels for each word, leaving the first row and column empty
    display.drawPixel(1 + x*3, 1 + y*3, color);
    display.drawPixel(1 + x*3, 2 + y*3, color);
    display.drawPixel(1 + x*3, 3 + y*3, color);
    display.drawPixel(2 + x*3, 1 + y*3, color);
    display.drawPixel(2 + x*3, 2 + y*3, color);
    display.drawPixel(2 + x*3, 3 + y*3, color);
    display.drawPixel(3 + x*3, 1 + y*3, color);
    display.drawPixel(3 + x*3, 2 + y*3, color);
    display.drawPixel(3 + x*3, 3 + y*3, color);  
}


// Main loop
void loop() {

  // Handle HTTP server requests
  server.handleClient();

  // Uptime calculation (calculate uptime in minutes)
  if (millis() - lastTick >= 60000) {            
    lastTick = millis();            
    uptime++;            
  }      

  // Check if NTP update is due (every hour)
  if ((millis() - NTPUpdateMillis >= 60*60*1000) && (!NTPRequested)) {  
    requestNTPUpdate();
  }    

  handleNTPResponse();

  // Handle MQTT connection/reconnection
  if (mqtt_server!="") {
    if (!mqtt.connected()) {
      reconnect();
    }
    mqtt.loop();
  }

  // regular clock display, light up the words
  if (updateScreen==1) {
    renderTime();
    calculateColors();
    updateWords();
    updateScreen = 0;
  }

  // random word animation every minute
  if (updateScreen==2) {
    if (millis()-lastANI>ANIMATION_WORD_DELAY) {
      if (aniSequence==0) {
        // clear the letters from the screen
        display.clearDisplay();
      }
      if (aniSequence>ANIMATION_WORD_COUNT-1) {
        updateScreen = 3;
        lastANI = millis();
        aniSequence = 0;
      } else {
        updateAnimation();
        lastANI = millis();
      }
    }
  }

  // pausing the screen for a second after the word animation
  if (updateScreen==3) {
    if (millis()-lastANI>1000) {
        updateScreen = 1;
        lastANI = millis();
        aniSequence = 0;
    }
  }

}

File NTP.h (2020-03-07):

/*
 ************** HEADER DECLARATION *************
#include <WiFiUdp.h>                // Added for NTP functionality
#include <Time.h>
#include <TimeLib.h>
#include <sunMoon.h>                // Sunrise, sunset calculation

 ************** Add to Setup *******************
  // Start UDP for NTP function
  Serial.println("Starting UDP");
  udp.begin(localPort);
  Serial.print("Local port: ");
  Serial.println(udp.localPort());
  requestNTPUpdate();
  // Initialize sunrise and sunset calculator
  sm.init(GMTOffset, sm_latitude, sm_longtitude);

 ************** Add to Loop ********************
  // Check if NTP update is due
  if ((millis() - NTPUpdateMillis >= 60*60*1000) && (!NTPRequested)) {  
    requestNTPUpdate();
  }    

  // Check for NTP response
  int cb = udp.parsePacket();
  if (cb!=0) {
    NTPUpdateMillis = millis();
    NTPRequested = false;
    udp.read(packetBuffer, NTP_PACKET_SIZE); // read the packet into the buffer
    unsigned long highWord = word(packetBuffer[40], packetBuffer[41]);
    unsigned long lowWord = word(packetBuffer[42], packetBuffer[43]);
    unsigned long secsSince1900 = highWord << 16 | lowWord;
    const unsigned long seventyYears = 2208988800UL;
    epoch = secsSince1900 - seventyYears;
    if (summerTime(epoch)) {
      epoch += 3600; // add 1 hour DST
    }
    epoch += GMTOffset * 60;
    Serial.print("NTP Update (epoch): ");
    Serial.println(epoch);
    Serial.print("NTP Update (time): ");
    printDate(epoch);  Serial.println("");

    // Sunrise and Sunset calculations
    time_t sRise = sm.sunRise(epoch);
    time_t sSet  = sm.sunSet(epoch);
    sRise += epoch / 86400L * 86400L;
    sSet += epoch / 86400L * 86400L;
    if (summerTime(epoch)) {
      sRise += 3600; // add 1 hour DST
      sSet += 3600; // add 1 hour DST
    }
    Serial.print("Today sunrise and sunset: ");
    printDate(sRise); Serial.print("; ");
    printDate(sSet);  Serial.println("");
  }  

 */
#include <sunMoon.h>                // Sunrise, sunset calculation

// Update the below global variables for your project
const char* ntpServerName = "hu.pool.ntp.org";
int GMTOffset = 60;                      // Offset to GMT time in minutes, CET: GMT+1 hour = 60 minutes
long sm_latitude = 47.44;                // Your coordinates, get it from: http://www.mapseasy.com/adress-to-gps-coordinates.php
long sm_longtitude = 19.02;

unsigned long NTPUpdateMillis = 0;       // Last time NTP update was received
bool NTPRequested = false;               // flag that NTP update requested
unsigned long epoch = 0;                 // Unix time received from NTP
unsigned int localPort = 2390;           // local port to listen for UDP packets
const int NTP_PACKET_SIZE = 48;         
byte packetBuffer[ NTP_PACKET_SIZE];

IPAddress timeServerIP;
WiFiUDP udp;
sunMoon  sm;

static const uint8_t monthDays[] = {31, 28, 31, 30, 31, 30, 31, 31, 30, 31, 30, 31};
#define LEAP_YEAR(Y) ( ((1970+Y)>0) && !((1970+Y)%4) && ( ((1970+Y)%100) || !((1970+Y)%400) ) )


struct  strDateTime
{
  byte hour;
  byte minute;
  byte second;
  int year;
  byte month;
  byte day;
  byte wday;
} ;

strDateTime DateTime;                      // Global DateTime structure, will be refreshed every Second

void printDate(time_t date) {
  char buff[20];
  sprintf(buff, "%02d-%02d-%4d %02d:%02d:%02d",
  day(date), month(date), year(date), hour(date), minute(date), second(date));
  Serial.print(buff);
}

void printTime(time_t date) {
  char buff[20];
  sprintf(buff, "%02d:%02d:%02d", hour(date), minute(date), second(date));
  Serial.print(buff);
}

strDateTime ConvertUnixTimeStamp( unsigned long _tempTimeStamp) {
  strDateTime _tempDateTime;
  uint8_t year;
  uint8_t month, monthLength;
  uint32_t time;
  unsigned long days;

  time = (uint32_t)_tempTimeStamp;
  _tempDateTime.second = time % 60;
  time /= 60; // now it is minutes
  _tempDateTime.minute = time % 60;
  time /= 60; // now it is hours
  _tempDateTime.hour = time % 24;
  time /= 24; // now it is days
  _tempDateTime.wday = ((time + 4) % 7) + 1;  // Sunday is day 1

  year = 0;
  days = 0;
  while ((unsigned)(days += (LEAP_YEAR(year) ? 366 : 365)) <= time) {
    year++;
  }
  _tempDateTime.year = year; // year is offset from 1970

  days -= LEAP_YEAR(year) ? 366 : 365;
  time  -= days; // now it is days in this year, starting at 0

  days = 0;
  month = 0;
  monthLength = 0;
  for (month = 0; month < 12; month++) {
    if (month == 1) { // february
      if (LEAP_YEAR(year)) {
        monthLength = 29;
      } else {
        monthLength = 28;
      }
    } else {
      monthLength = monthDays[month];
    }

    if (time >= monthLength) {
      time -= monthLength;
    } else {
      break;
    }
  }
  _tempDateTime.month = month + 1;  // jan is month 1
  _tempDateTime.day = time + 1;     // day of month
  _tempDateTime.year += 1970;

  return _tempDateTime;
}

//
// Summertime calculates the daylight saving time for middle Europe. Input: Unixtime in UTC
//
boolean summerTime(unsigned long _timeStamp ) {
  strDateTime  _tempDateTime = ConvertUnixTimeStamp(_timeStamp);
  // printTime("Innerhalb ", _tempDateTime);

  if (_tempDateTime.month < 3 || _tempDateTime.month > 10) return false; // keine Sommerzeit in Jan, Feb, Nov, Dez
  if (_tempDateTime.month > 3 && _tempDateTime.month < 10) return true; // Sommerzeit in Apr, Mai, Jun, Jul, Aug, Sep
  if (_tempDateTime.month == 3 && (_tempDateTime.hour + 24 * _tempDateTime.day) >= (3 +  24 * (31 - (5 * _tempDateTime.year / 4 + 4) % 7)) || _tempDateTime.month == 10 && (_tempDateTime.hour + 24 * _tempDateTime.day) < (3 +  24 * (31 - (5 * _tempDateTime.year / 4 + 1) % 7)))
    return true;
  else
    return false;
}

// send an NTP request to the time server at the given address
unsigned long sendNTPpacket(IPAddress& address)
{
  Serial.println("Sending NTP packet...");
  // set all bytes in the buffer to 0
  memset(packetBuffer, 0, NTP_PACKET_SIZE);
  // Initialize values needed to form NTP request
  // (see URL above for details on the packets)
  packetBuffer[0] = 0b11100011;   // LI, Version, Mode
  packetBuffer[1] = 0;     // Stratum, or type of clock
  packetBuffer[2] = 6;     // Polling Interval
  packetBuffer[3] = 0xEC;  // Peer Clock Precision
  // 8 bytes of zero for Root Delay & Root Dispersion
  packetBuffer[12]  = 49;
  packetBuffer[13]  = 0x4E;
  packetBuffer[14]  = 49;
  packetBuffer[15]  = 52;

  // all NTP fields have been given values, now
  // you can send a packet requesting a timestamp:
  NTPRequested = true;
  udp.beginPacket(address, 123); //NTP requests are to port 123
  udp.write(packetBuffer, NTP_PACKET_SIZE);
  udp.endPacket();
}

void requestNTPUpdate() {
  WiFi.hostByName(ntpServerName, timeServerIP); 
  Serial.print("Requesting NTP update from ");
  Serial.println(timeServerIP);
  sendNTPpacket(timeServerIP);  
}
